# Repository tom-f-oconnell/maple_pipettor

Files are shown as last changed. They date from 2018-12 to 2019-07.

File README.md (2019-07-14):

### maple_pipettor

Unscrew the vacuum cup from that MAPLE effector, and screw an adapter in between
that thread (1/8" NPT in original MAPLE designs) and whatever tubing you want to
use. This could be either a thread->barb or thread->Luer adapter. Insert a Luer
lock into the custom serological pipette adapter. Run a line, with a filter in
it if you want, between the manifold and the Luer lock on the serological
pipette adapter.

Attach the serological pipette mount to the two outer, unused, mounting holes
above the vacuum cup manifold. Clamp it down on the pipette you want to use.

In place of the fly manipulator effector, attach a servo gripper, via a custom
adapter. Attach the pin normally used to control the fly manipulator vacuum to
the servo control input.

Use two 1-10K resistors to divide the 12V (any reason to divide the 12V? or just
also use the 5V for the signal too? (would probably still need some resistors,
to not just short that power supply)

The gripper is for moving scintillation vials on and off of the scale, and the
serological pipette is for filling the vials on the scale, using a stock vial
somewhere else in the workspace.

#### TODO
Should make it so the user is prompted for a target mass when `aliquot.py`
is run, or maybe allow setting the mass through configuration.

Is there appropriate supply voltage for the servo already on the breakout board
somewhere, or will I have to build that in somewhere?
Check the 5v providing power to the pressure sensor can supply the ~800mA stall
current (maybe higher at 5v rather than 6v?).

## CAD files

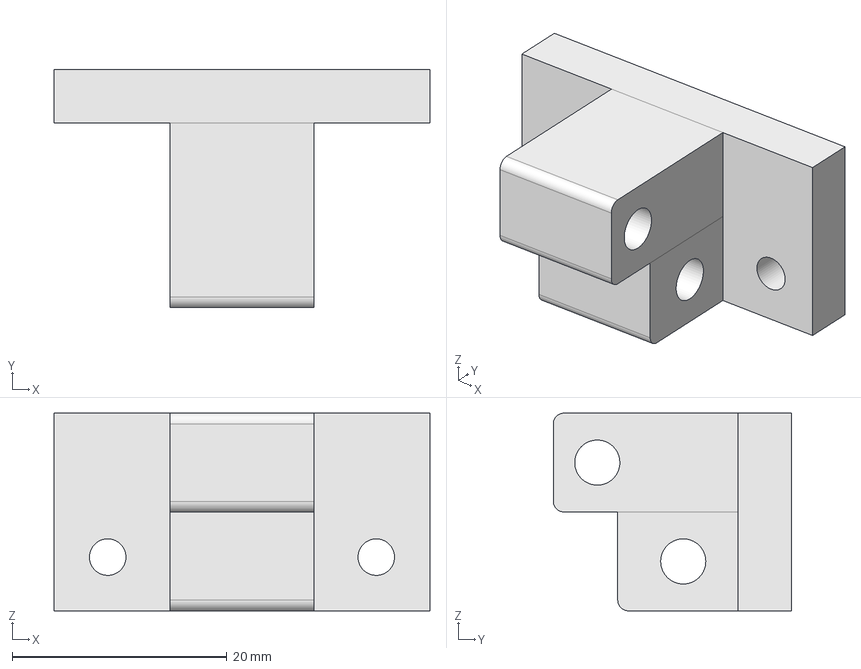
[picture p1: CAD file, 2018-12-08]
gripper_mount.fcstd
35.0 x 22.2 x 18.4 mm

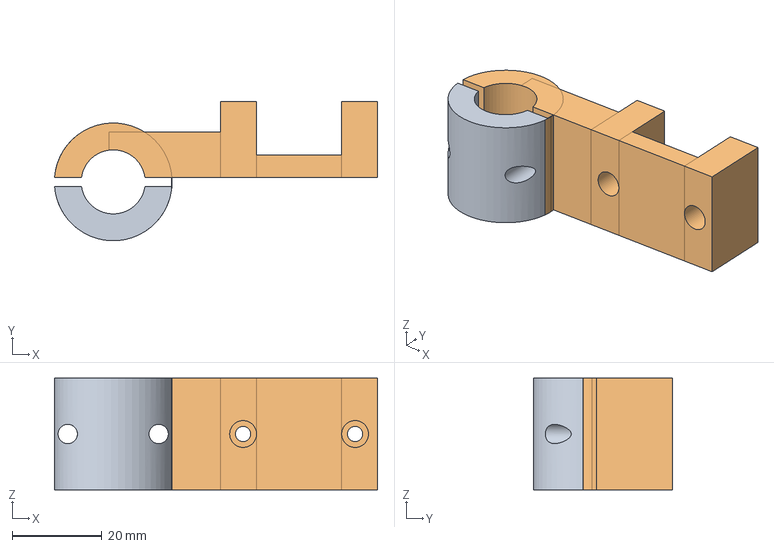
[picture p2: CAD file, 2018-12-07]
pipette_mount.fcstd
72.1 x 31.1 x 25.0 mm
lone_clamp_half_with_holes
pipette_clamp_and_mount

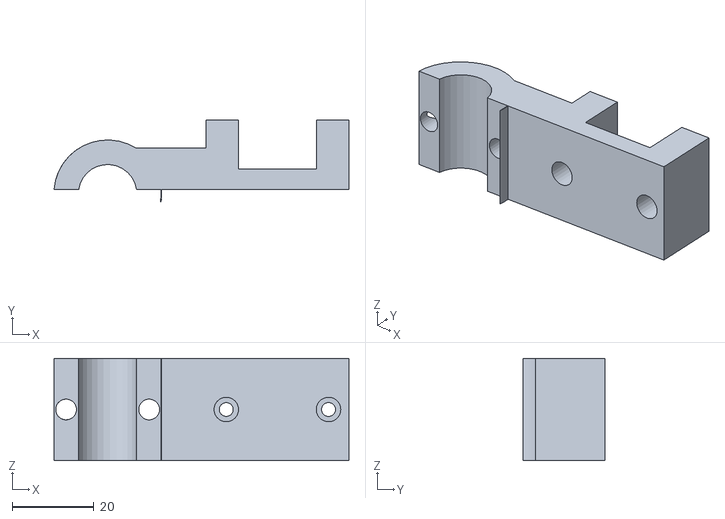
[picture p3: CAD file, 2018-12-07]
pipette_clamp_and_support.stl
72.1 x 20.0 x 25.0

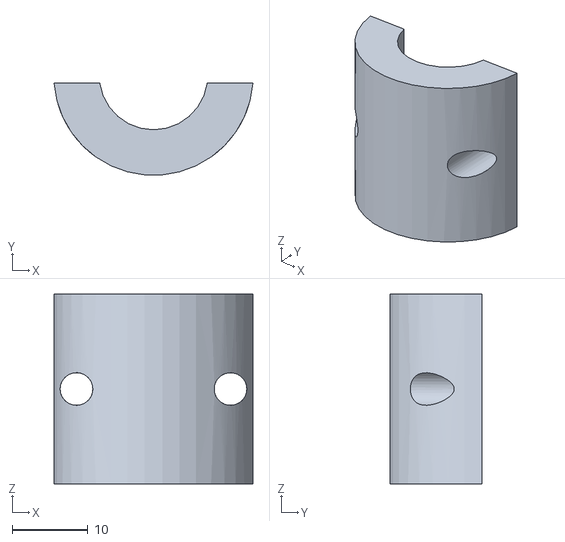
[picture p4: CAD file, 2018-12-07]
lone_clamp_half_with_holes.stl
26.2 x 12.1 x 25.0

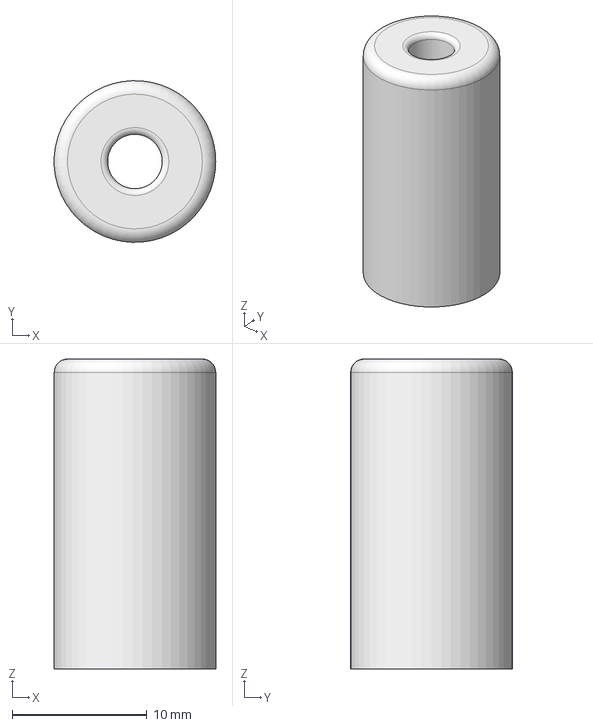
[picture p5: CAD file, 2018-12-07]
serological_to_thread.fcstd
12.0 x 12.0 x 23.0 mm

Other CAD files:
gripper_mount.stl
serological_to_thread.stl

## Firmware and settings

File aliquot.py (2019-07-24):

#!/usr/bin/env python

"""
Script to use MAPLE, with a scale and some purpose-built effectors, to aliquot
out liquids by mass with a serological pipette.
"""

from __future__ import print_function
from __future__ import division

import os
import sys
import time
from datetime import datetime

import numpy as np
import maple
import maple.robotutil
import maple.module

import wpi_al1000


try:
    input = raw_input
except NameError:
    pass


def move_gripper_servo(robot, s_position):
    """
    Supposedly S5 is fully to the left and S10 is fully to the right...
    So how is S0 "off"? Less than 5? More than 10? Interpretation of the #?

    According to reprap docs: "`Snnn` Angle or microseconds"

    Empirically:
    S2.7 seems about fully open (2.5 strains a little)
    S11.1 seems most closed, non-strained, position w/ (1/16"?) Viton pads
    S11.25 will strain them a little

    Requires different Smoothieware configuration than default MAPLE.
    Use smoothie_config in this repository.
    """
    # TODO add trailing newline in sendSyncCmd/sendCmd automatically
    cmd = 'M280 S{}\n'.format(s_position)
    robot.smoothie.sendSyncCmd(cmd)


def grip_vial(robot, pos=4.3):
    # 4.3 might help keep the vial slightly straigher than 4.5?
    # it is definitely a little looser
    move_gripper_servo(robot, pos) #, 4.3) #4.5)
    # TODO min delay that is appropriate?
    robot.dwell_ms(1000)


def release_vial(robot):
    move_gripper_servo(robot, 2.65) # 2.7


# TODO see choice module implementation of array subclass, to see whether i
# changed the api
class ScintillationVialBox(maple.module.Array):
    """
    """
    def __init__(self, robot, offset, vial_grip_height,
        calibration_approach_from=None, verbose=False):
        """
        #vial_grip_height: how high up from worksurface vial should be gripped,
        #    if vial were resting on worksurface
        vial_grip_height: defined w/ 0 as home point on Z2, and positive going
            down, now; for simplicity.
        """
        gripper_working_height = vial_grip_height
        # TODO calc offset from full bounds anyway prob, and just adjust based
        # on these bounds?
        # TODO TODO TODO go back to only using interior stuff. edge can be too
        # risky, since it's not always as tightly on the grid
        start_letter = 'D'
        end_letter = 'J'
        start_num = 2
        end_num = 9

        # TODO could switch them... (if making kwarg of init)
        assert start_letter <= end_letter
        assert start_num <= end_num

        self.letters = [chr(x) for x in
            range(ord(start_letter), ord(end_letter) + 1)][::-1]
        self.nums = list(range(start_num, end_num + 1))

        # trying to only visit interior regions, since the flaps are less likely
        # to flip the vial when replacing it, since they are supported on all
        # sides, and thus less likely to get bent
        n_cols = len(self.letters) #6
        n_rows = len(self.nums) #7

        # The taller two edges of the box are 64mm.
        # TODO how did i come to (100, 100, 40)? mm, right? (same w/ (5,5) for
        # to_first_anchor)
        full_box_dim = 290
        extent = (
            (n_cols / 10) * full_box_dim,
            (n_rows / 10) * full_box_dim,
            64
        )
        # TODO default to extent (- 2*border) divided by cols/rows
        # TODO maybe w/ a border variable (not sure it's reasonable to assume
        # that would be zero, given how i'm using extent as actual size of thing
        # in workspace)
        anchor_spacing = extent[0] / n_cols
        # TODO TODO have this default to assuming the grid centers are symmetric
        # about the module extent center (not z of course), in maple Array def
        to_first_anchor = anchor_spacing / 2.0

        super(ScintillationVialBox, self).__init__(robot, offset, extent,
            gripper_working_height, n_cols, n_rows, to_first_anchor,
            anchor_spacing, loaded=True,
            calibration_approach_from=calibration_approach_from)

        # TODO remove this / any need for this in maple module, if there still
        # is any
        self.z0_working_height = 45.0

        # TODO use self.full for vial presence or whether vial has been filled
        # or what?
        # support less than full box? support different amounts in some?
        # separate state variables for vial presence and fill status?


    # TODO TODO delete the this testing logic / move into maple
    # (just disable z? i have one other comment on this somewhere)
    testing = False
    #testing = True
    test_buffer = 20
    def get(self, xy, ij):
        """Moves to a vial and picks it up.
        """
        # TODO TODO factor working distance z travels into parent class
        # (otherwise little point in the shared instance variable)
        # TODO rename latter to z2_.. in maple
        #zw = self.robot.z2_to_worksurface - self.flymanip_working_height
        # (for simplicity, using smoothie coords now)
        zw = self.flymanip_working_height
        if self.testing:
            zw -= self.test_buffer
            zw = max(zw, 0)

        self.robot.moveXY(xy)

        # TODO assert we aren't carrying a vial or something?
        # do something like that in array by default?
        # (should work same way w/ flies)
        # To open grippers so they can fit around the vial.
        release_vial(self.robot)

        self.robot.moveZ2(zw)

        grip_vial(self.robot)

        # Although all get/put calls get flanked by moving effectors to travel
        # height, need to move higher when we are holding a vial, as otherwise
        # it would crash into the box when moving.
        #zvial = zw - self.flymanip_working_height - 3
        # (to simplify things for now)
        zvial = 0
        self.robot.moveZ2(zvial)


    def put(self, xy, ij):
        """Moves to a (presumed empty) space in the box and releases the vial.
        """
        #zw = self.robot.z2_to_worksurface - self.flymanip_working_height - 2
        # (for simplicity, using smoothie coords now)
        zw = self.flymanip_working_height - 1
        if self.testing:
            zw -= self.test_buffer
            zw = max(zw, 0)

        self.robot.moveXY(xy)
        self.robot.moveZ2(zw)
        release_vial(self.robot)
        # also just using absolute smoothie coords for simplicity for now,
        # rather than rely on auto return (current offsets, like z2_to_w...
        # are wrong and would cause crashes)
        self.robot.moveZ2(12)


    def coord_label(self, i, j):
        return self.letters[i], self.nums[j]


if __name__ == '__main__':
    weigh_aliquots = True
    print('Vialbox should be oriented so the side facing you reads A-J')

    # TODO is this not the default config? just defer to whatever default
    # settings there are, whether this file or something else?
    robot = maple.robotutil.MAPLE(os.path.join(maple.__path__[0], 'MAPLE.cfg'),
        enable_z0=False, enable_z1=False, z2_has_crash_sensor=False)#, home=False)
    # TODO TODO put these hardcoded offsets in some config? some override config
    # where central config still does most stuff?
    # TODO provide defaults in maple config even? or maybe have 0 at top if 
    # none provided? or have that as another mode?

    # TODO TODO replace all other places that use "if robot is None"
    # check for dry run w/ some mock robot class / dryrun flag in robotutil
 
    # TODO are the lhs and vial_grip_height really interacting as i want?
    # shouldn't changing vial_grip_height not affect where worksurface is
    # defined?
    vial_grip_height = 59.5
    # 60 is about as far down as i want the z axis to go
    # TODO try to only go to to 58 intead of 60 (vial_grip_height is subtracted
    # off when computing working height for gripper)? may need to change some
    # other values to avoid limit when going up.
    # 62 def holds vial a little straighter than 60 (w/ vial_grip_height=58),
    # but pushes on box edges a little. any less work?
    # 61 doesn't work that well.
    #robot.z2_to_worksurface = 60 + vial_grip_height
    # currently just used for automatic return in module get_/put_
    robot.z2_to_worksurface = 118

    correction_x = -3
    correction_y = 0
    vialbox_offset = (754 + correction_x, -14.5 + correction_y)
    vialbox = ScintillationVialBox(robot, vialbox_offset, vial_grip_height)
    # TODO delete
    '''
    wrong_ijs = [(n // vialbox.n_cols, n % vialbox.n_rows) for n in range(20)]
    wrong_lines = [', {0}, {1[0]}, {1[1]}, , '.format(n,
        vialbox.coord_label(i, j)) for n, (i, j) in enumerate(wrong_ijs)]
    print('\n'.join(wrong_lines))
    ijs = [(n // vialbox.n_rows, n % vialbox.n_rows) for n in range(20)]
    lines = [', {0}, {1[0]}, {1[1]}, , '.format(n,
        vialbox.coord_label(i, j)) for n, (i, j) in enumerate(ijs)]
    print('correct:')
    print('\n'.join(lines))
    import ipdb; ipdb.set_trace()
    '''
    #

    # TODO TODO probably refactor calibration_approach_from into just
    # approach_from, which is used in calibration and during motions, for
    # best applicability of calibration, or for controlling backlash w/o
    # calibration. w/ separate flag to calibrate?

    # In hopes that after controlling backlash a little, the gripper can be
    # centered on each vial a little better, maybe making things reliable
    # enough. Using a corner for the most consistent approach directions.
    approach_from = vialbox.anchor_center(0, 0)

    release_vial(robot)
    robot.moveZ2(0)

    syringepump_xy = (632, 179)
    syringepump_z = 22
    if weigh_aliquots:
        pump_xy_approach = [
            (syringepump_xy[0], 160)
        ]
    else:
        pump_xy_approach = [
            (660, 160),
            (syringepump_xy[0], 160)
        ]

    # TODO should err if pump is off (right now, seems to still be able to open
    # serial connection?)
    pump = wpi_al1000.AL1000(port='/dev/ttyUSB0')

    cc_str = input('Size of syringe in mL (default=60)? ')
    cc = 60
    if len(cc_str) != 0:
        cc = int(cc_str)

    if cc == 60:
        print('Assuming the 60mL syringe is a BD plastic syringe!')
        family = 'B-D'
    elif cc == 20:
        print('Assuming the 20mL syringe is a Norm-Ject plastic syringe ' +
            '(marked HSW)!')
        family = 'NORM-JECT'

    capacity_str = input('What volume of pfo (mL) is in the syringe (round ' +
        'DOWN) (default=syringe capacity)? ')
    if len(capacity_str) != 0:
        capacity = float(capacity_str)
        pump.capacity = capacity

    pump.set_syringe(family=family, cc=cc)
    drop_wait_s = 20
    def fill_vial(vol_ml):
        """Moves vial under syringe pump output.
        Assumes Z2 is at appropriate travel height already.
        """
        have_vol = pump.can_dispense(vol_ml)
        if not have_vol:
            input('Re-fill syringe and press Enter to continue...')
            pump.clear_vol_disp()

        for xy in pump_xy_approach:
            robot.moveXY(xy)
        # Only doing this after gripper is no longer over box,
        # as a good height here might crash into box.
        robot.moveZ2(syringepump_z)
        robot.moveXY(syringepump_xy)
        
        pump.dispense(vol_ml)
        print('Waiting {} seconds for drops to fall... '.format(drop_wait_s),
            end='')
        sys.stdout.flush()
        time.sleep(drop_wait_s)
        print('done')

        robot.moveXY(pump_xy_approach[-1])
        #zvial_travel = robot.z2_to_worksurface - 2 * vial_grip_height - 3
        # (to simplify things for now)
        zvial_travel = 0
        robot.moveZ2(zvial_travel)
        for xy in pump_xy_approach[:-1][::-1]:
            robot.moveXY(xy)

    if weigh_aliquots:
        from mettler_toledo_device import MettlerToledoDevice
        scale = MettlerToledoDevice(port='/dev/ttyUSB2')

        # TODO some scale command to automate this? setting to make it not
        # sleep?
        print('Tap the scale to wake it up, if it is not already.')
        #
        zeroed = False
        # TODO this doesn't seem to work if we can't wake the scale...
        print('Waiting for stable weight to zero... ', end='')
        sys.stdout.flush()
        while not zeroed:
            zeroed = scale.zero_stable()
        print('done')

        scale_xy = (632, 2)
        # 23 would stick sometimes
        scale_z = 23

        def weigh_vial():
            """Returns vial weight in grams. Assumes start at safe Z height.
            """
            # just to be safe. could delete later.
            robot.moveZ2(0)
            #
            robot.moveXY(scale_xy)
            robot.moveZ2(scale_z - 0.5)

            release_vial(robot)
            robot.moveZ2(0)
            time.sleep(1)
        
            ret = None
            print('Waiting for stable weight... ', end='')
            sys.stdout.flush()
            while ret is None:
                # 2-list w/ float value and str repr of unit (e.g. 'g')
                # None if weight is not stable.
                ret = scale.get_weight_stable()
            print('done')

            weight = ret[0]
            assert ret[1] == 'g', \
                'expected scale units in grams (got {})'.format(ret[1])

            robot.moveZ2(scale_z)
            grip_vial(robot)

            #zvial_travel = robot.z2_to_worksurface - 2 * vial_grip_height - 3
            # (to simplify things for now)
            zvial_travel = 0
            robot.moveZ2(zvial_travel)

            return weight

    # TODO delete
    # TODO prompt to integrate this as an optional check before starting
    # (and how to make accept / reject / correction entry user friendly?)
    """
    robot.moveZ2(0)
    points = 4
    for x in range(vialbox.n_cols // 2):
        for y in range(vialbox.n_rows // 2):
            for corner in range(4):
                if corner == 0:
                    i = x
                    j = y
                elif corner == 1:
                    i = x
                    j = vialbox.n_rows - y - 1
                elif corner == 2:
                    i = vialbox.n_cols - x - 1
                    j = y
                elif corner == 3:
                    i = vialbox.n_cols - x - 1
                    j = vialbox.n_rows - y - 1
                print(i, j)
                ix, jy = vialbox.anchor_center(i, j)
                print(ix, jy)
                # To keep backlash more consistent.
                robot.moveXY(approach_from)
                robot.moveXY((ix,jy))
                # TODO this ok?
                robot.moveZ2(30)
                #
                import ipdb; ipdb.set_trace()
                points -= 1
                if points <= 1:
                    break
                '''
                vialbox.get_indices(i, j)

                #robot.moveXY(approach_from)
                vialbox.put_indices(i, j)
                import ipdb; ipdb.set_trace()
                '''
    robot.moveZ2(0)
    """

    # TODO TODO allow user to answer questions while robot is homing

    # rates as low as 2 have caused slipping in my use case
    # (maybe also 1.5?)
    max_rate = 1.5
    rate = 1.2
    rate_str = input('Pumping rate (mL/min) (default={}, max={})? '.format(
        rate, max_rate))
    if len(rate_str) != 0:
        rate = float(rate_str)
        if rate < 0 or rate > max_rate:
            raise ValueError('rate must be between 0 and {}'.format(max_rate))

    pump.set_rate(rate, unit='MM')
    remote_rate = pump.get_rate()
    print('Using rate of {} mL/min'.format(remote_rate))

    vol_str = input('Target volume (mL) (default=2.00)? ')
    # Just pressing Enter yields and empty string (at least in Python 2)
    if len(vol_str) == 0:
        target_vol_ml = 2.0
    else:
        # TODO also err if out of some range / too many sig figs?
        target_vol_ml = float(vol_str)

    cv = 0.02
    # TODO option to always use const cv?
    cv_str = input('Initial volume correction (mL, added to target volume) ' +
        '(default={})? '.format(cv))
    if len(cv_str) != 0:
        cv = float(cv_str)
    vol_ml = target_vol_ml + cv

    max_aliquots = vialbox.n_cols * vialbox.n_rows
    # TODO TODO maybe make the default the max given vol in syringe?
    n_str = input('Number of aliquots (default=20)? ')
    n_aliquots = 20
    if len(n_str) != 0:
        n_aliquots = int(n_str)
        if n_aliquots < 0:
            raise ValueError('number of aliquots must be positive')
        elif n_aliquots > max_aliquots:
            raise ValueError('number of aliquots can not exceed # of reachable '
                + 'vials ({})'.format(max_aliquots))

    empty_vial_weights = np.empty((vialbox.n_cols, vialbox.n_rows))
    empty_vial_weights[:] = np.nan
    pfo_weights = np.empty((vialbox.n_cols, vialbox.n_rows))
    pfo_weights[:] = np.nan

    if weigh_aliquots:
        csv_file = 'aliquot_masses.csv'
        print('Will write aliquot weight data to {}'.format(csv_file))
        run_start_timestamp = datetime.now()
        # TODO use multiline str syntax
        header = ('run_start_timestamp, n, col, row, empty_vial_g, pfo_g' +
            ', target_vol, syringe_cc, syringe_family, rate, ' +
            'vol_correction, drip_wait, start_syringe_vol, vol_from_mass, ' +
            'num_this_run, time_taken\n')
        line_fmt_str = ', '.join(['{}'] * len(header.split(','))) + '\n'

        if not os.path.exists(csv_file):
            # TODO maybe also replace header if differs / move existing
            # file to some backup location in that case and then make a new one
            # w/ current header
            # TODO stop saving n?
            with open(csv_file, 'w') as f:
                f.write(header)

    # TODO TODO calculate and print total time program will take

    # TODO delete after getting to save state
    start_n_str = input('Last completed aliquot # of previous run ' +
        '(leave blank to start program program from beginning)? ')
    start_n = 0
    if len(start_n_str) != 0:
        # TODO maybe just get max from aliquot_masses.txt?
        start_n = int(start_n_str) + 1

    # TODO need to account for cv? read from csv?
    # (since pump get_vol_disp seems to reset across serial sessions)
    pump.capacity = pump.capacity - (target_vol_ml * start_n)
    # TODO delete
    print('assuming syringe currently has vol of:', pump.capacity)
    #

    # TODO allow this to be configurable?
    pfo_density_g_ml = 0.85
    target_mass = target_vol_ml * pfo_density_g_ml
    # TODO delete print
    print('target mass:', target_mass)
    #

    #
    # TODO TODO TODO also save enough extra info to csv to use it to calculate
    # appropriate calibrations (probably at least amt in syringe (maybe
    # adjusting as stuff is aliquoted w/in a run), **correction factor**, wait
    # times, rate[, possible to get whether scale is level from api?])
    num_this_run = 0
    last_time = time.time()
    for n in range(start_n, n_aliquots):
        # TODO check this
        curr_syringe_vol = pump.capacity - (num_this_run * start_n)

        print('Aliquot #{}'.format(n))
        i = n // vialbox.n_rows
        j = n % vialbox.n_rows
        col_letter, row_num = vialbox.coord_label(i, j)
        print('{}{} (i={}, j={})'.format(col_letter, row_num, i, j))

        # To keep backlash more consistent.
        robot.moveXY(approach_from)
        # Grips a vial and moves to working height.
        vialbox.get_indices(i, j)

        if weigh_aliquots:
            empty_vial_g = weigh_vial()
            print('empty vial weight:', empty_vial_g)
            empty_vial_weights[i, j] = empty_vial_g

        # TODO maybe make a platform for vial so the manipulator can do either
        # things while (slow) pump is pumping?
        fill_vial(vol_ml)

        if weigh_aliquots:
            full_vial_g = weigh_vial()
            pfo_g = full_vial_g - empty_vial_g
            print('pfo weight: {} g'.format(pfo_g))
            pfo_weights[i, j] = pfo_g

            # TODO set err thresh based on some relative deviation from expected
            # mass, given density of pfo? (and like print the list of those that
            # passed?)

            # TODO maybe bound cv in case there is an erratic scale reading?
            # TODO check this formula...
            '''
            #cv = target_vol_ml - vol_from_mass
            cv = vol_ml - vol_from_mass
            #vol_ml = target_vol_ml + (target_vol_ml - vol_from_mass)
            #vol_ml = target_vol_ml + (vol_ml - vol_from_mass)
            vol_ml = target_vol_ml + cv
            '''
            vol_from_mass = pfo_g / pfo_density_g_ml
            mass_err = target_mass - pfo_g
            cv = mass_err / pfo_density_g_ml
            # TODO check this is what i want
            # TODO TODO TODO i don't think this is exactly what i want
            # (if commanded vol from previous aliquot produced no error,
            # we should keep the same commanded vol, and thus cv, whether
            # cv == 0 or not)
            # (until resolved, should switch back to constant cv)
            # TODO TODO TODO keep some kind of running average / filtered
            # estimate of cv
            vol_ml = target_vol_ml + cv
            # TODO probably delete these prints
            print('pfo vol from mass: {:.2f} mL'.format(vol_from_mass))
            print('mass_err: {:.2f}'.format(mass_err))
            print('using new vol correction of: {:.2f}'.format(cv))
            print('new commanded volume: {:.2f}'.format(vol_ml))
            #

        # To keep backlash more consistent.
        robot.moveXY(approach_from)
        vialbox.put_indices(i, j)

        curr_time = time.time()
        time_taken = curr_time - last_time
        last_time = curr_time
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

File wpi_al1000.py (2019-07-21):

#!/usr/bin/env python

"""
This module implements a driver for the AL1000 syringe pump from World Precision
Instruments.

(adapted from github.com/CINF/PyExpLabSys/blob/1412979/PyExpLabSys/drivers,
 which is distributed under the GPLv3 license)
"""

from __future__ import print_function

import sys
import time
import warnings

import serial
import crc16


def _format_float(num):
    """Returns str w/ float formatted as per the manual.
    From the manual:
    'Maximum of 4 digits plus 1 decimal point. Maximum of 3 digits to the
    right of the decimal point'
    """
    if num >= 10000:
        raise ValueError('floats sent to AL-1000 can only have 4 digits')
    # TODO it doesn't err if there is nothing to right of decimal point,
    # does it? test
    return '{:.3f}'.format(num)[:5]


class AL1000(object):
    """Driver for the AL1000 syringe pump"""
    
    def __init__(self, port="/dev/ttyUSB0", baudrate=19200):
        # TODO does this need to be changed for safe mode?
        self.serial = serial.Serial(
            port=port, baudrate=baudrate, timeout=1,
            parity=serial.PARITY_NONE,
            bytesize=serial.EIGHTBITS,
            stopbits=serial.STOPBITS_ONE,
            
        )
        self.safe_mode = False

        self.capacity = None
        self.max_rate = None
        self.min_rate = None

    def _send_command(self, command):
        # TODO switch all communication to safe mode protocol once i get that
        # working
        '''
        encoded_cmd = command.encode('ascii')
        # TODO how did octopus get away w/ {:s} for crc? it is bytes type for
        # me and that fails w/ non-empty format str
        length = '{:c}'.format(len(encoded_cmd) + 4).encode('ascii')
        crc = crc16.crc16xmodem(encoded_cmd)
        encoded_crc = crc.to_bytes(2, byteorder='big')
        # TODO do we actually wand b'\x03' suffix? octopus doesn't seem to
        to_send = length + encoded_cmd + encoded_crc # + b'\x03'
        # TODO delete
        print('sending:', to_send)
        #
        self.serial.write(to_send)
        time.sleep(0.5)
        # TODO need both of these calls? won't read by itself read
        # everything in waiting?
        waiting = self.serial.inWaiting()
        reply = self.serial.read(waiting)

        print('length of reply:', waiting)
        print('reply:', reply)

        # FIXME implement crc16 checksum check
        # TODO copy from octopus repo
        
        # TODO need to at least discard crc data to have replies be the
        # same?

        # this should be the firmware version: NE1000V3.928
        import ipdb; ipdb.set_trace()

        ret = reply.decode('ascii')

        # TODO TODO TODO are replies to safe mode commands in diff format?
        return ret[4:-1]
        '''
        formatted_command = command + "\r"
        self.serial.write(formatted_command.encode("ascii"))
        time.sleep(0.5)
        waiting = self.serial.inWaiting()
        reply = self.serial.read(waiting)
        try:
            reply_unicode = reply.decode("ascii")
            return reply_unicode[4:-1]
        except UnicodeDecodeError as err:
            print('command:', command)
            print('reply:', reply)
            raise

    def get_firmware(self):
        """Returns the str firmware version
        """
        # TODO on first run one time, '?R' was returned,
        # but after that, 'NE1000V3.928' was... wait untli ?R isn't returned?
        # what does that code mean?
        return self._send_command("VER")

    def get_diam(self):
        """Returns the syringe diameter in mm
        """
        return float(self._send_command('DIA'))

    def set_diam(self, diameter, warn=True):
        """Sets the syringe diameter in mm

        From the manual:
        Setting the syringe diameter also sets the units for 'Volume to be
        Dispensed' and 'Volume Dispensed'
        """
        if warn:
            warnings.warn('use set_syringe to get rate bounds checking')

        # TODO need to handle other things this changes (as docstring)?
        # TODO limit precision?
        # TODO TODO can this take a unit string suffix as w/ rate?
        return self._send_command('DIA' + _format_float(diameter))

    def get_rate(self):
        """Returns the pump rate in mL/min
        """
        ret = self._send_command("RAT")
        try:
            rate = float(ret[:-2])
        # For the case where the return value is something other than the rate
        # string, like some error code.
        except ValueError:
            print('Unexpected reply to rate request:', str(ret))
            raise

        vol_unit_char = ret[-2]
        time_unit_char = ret[-1]
        if vol_unit_char == 'U':
            rate = rate / 1000.0
        elif vol_unit_char != 'M':
            raise ValueError('unexpected volume unit code: {}'.format(
                vol_unit_char))

        if time_unit_char == 'H':
            rate = rate / 60.0
        elif time_unit_char != 'M':
            raise ValueError('unexpected time unit code: {}'.format(
                time_unit_char))

        return rate

    # TODO does this automatically get limited by current diam according to
    # table in manual? or should i implement that here? err if outside range?
    def set_rate(self, num, unit=False):
        # TODO is 34.38 actually as high as it goes? if so, raise appropriate
        # error code here
        """Sets the pump rate.
        
        Args:
            num (float): The flow rate (0 mL/min - 34.38 mL/min)
            unit (str): For valid values see below.
        
        Valid units are:
        UM=microL/min
        MM=milliL/min 
        UH=microL/hr 
        MH=milliL/hour
        """
        if self.max_rate is None:
            warnings.warn('use set_syringe before set_rate to get rate ' +
                'bounds checking')
        else:
            # TODO include my ~viscosity state var in check here too
            if num > self.max_rate:
                raise ValueError('rate > maximum for this syringe')

            if num < self.min_rate:
                raise ValueError('rate < minimum for this syringe')

        # TODO is False an appropriate default here? what's it mean?
        # is it not just selecting one of the other units?
        # should this even be supported?
        if unit == False:
            self._send_command("FUNRAT")
            return self._send_command("RAT" + _format_float(num))
        else:
            self._send_command("FUNRAT")
            return self._send_command("RAT" + _format_float(num) + unit)
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

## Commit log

2018-12-07 Added README draft and design files for all but servo mount
    [lone_clamp_half_with_holes.stl, pipette_clamp_and_support.stl, pipette_mount.fcstd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]
2018-12-07 Fixed M3 hole spacing on pipette clamp, added head clearance, made arm 1cm longer.
    [pipette_clamp_and_support.stl, pipette_mount.fcstd]
2018-12-08 Added gripper mount files.
    [gripper_mount.fcstd, gripper_mount.stl]
2019-04-14 Added smoothie config w/ fly manip vac changed to servo.
2019-07-14 Gripping + syringe pump dispensing almost working.
2019-07-15 Version working to grasp each vial in full box. WIP on pump + integration + interface.
2019-07-21 First version working fully correctly, w/ reasonably clean CLI.
    [aliquot.py, wpi_al1000.py]
2019-07-21 Oops. Homing at start now.
2019-07-24 Saving more data for future calibrations across more conditions + time ests. Current vol compensation not ideal.
